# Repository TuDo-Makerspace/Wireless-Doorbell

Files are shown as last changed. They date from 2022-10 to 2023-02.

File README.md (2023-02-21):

# TU-DO Wireless Doorbell <!-- omit in toc -->

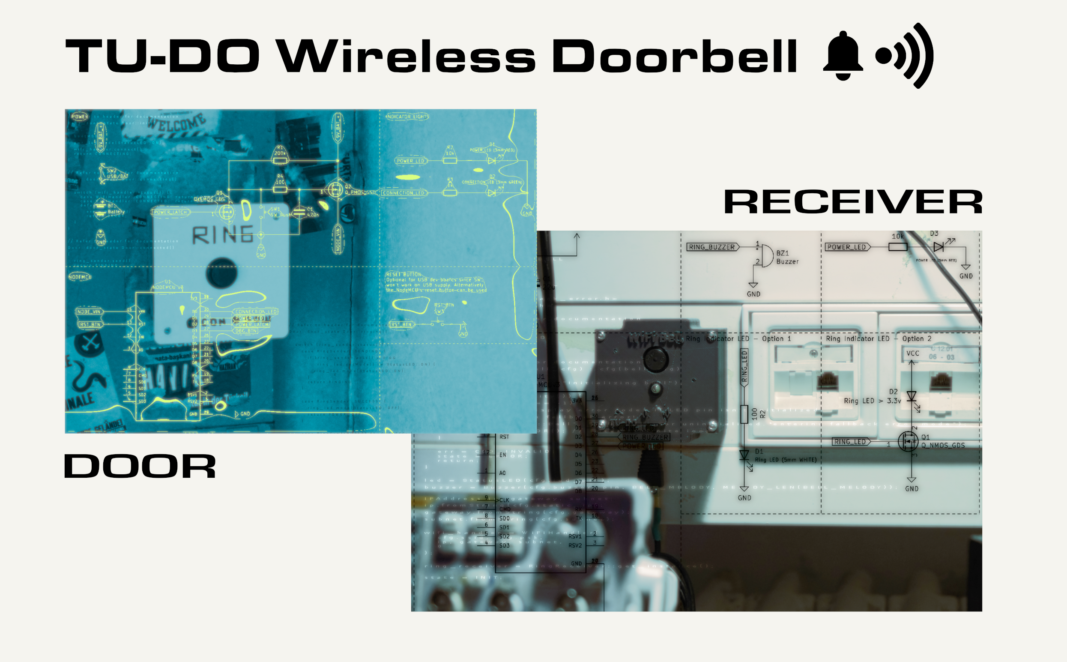
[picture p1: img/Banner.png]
Banner


A wireless doorbell based on the ESP8266

## Table Of Contents <!-- omit in toc -->

- [Overview](#overview)
	- [Doorbell Board](#doorbell-board)
	- [Receiver Board](#receiver-board)
- [Gerbers, BOMs, and Assembly](#gerbers-boms-and-assembly)
- [Configuring the Firmware and Flashing the Boards](#configuring-the-firmware-and-flashing-the-boards)
- [Firmware Structure](#firmware-structure)
- [License](#license)

## Overview

The TU-DO Wireless Doorbell is an open source and open hardware doorbell which runs over WiFi. The project utilizes the ESP8266 microcontroller, and includes two boards, one for the doorbell button and the other for the receiver.

### Doorbell Board

The doorbell board (also refered to as the "Door" board) is designed to be placed at the door and features a button to trigger the doorbell ring. It is powered by a 9V battery for easy installation.

The circuit of the doorbell board consists of:
- A button for triggering the doorbell ring
- Two indicator LEDs (one red and one green)
- An ESP8266 microcontroller
- A 9V battery
- A MOSFET power latch

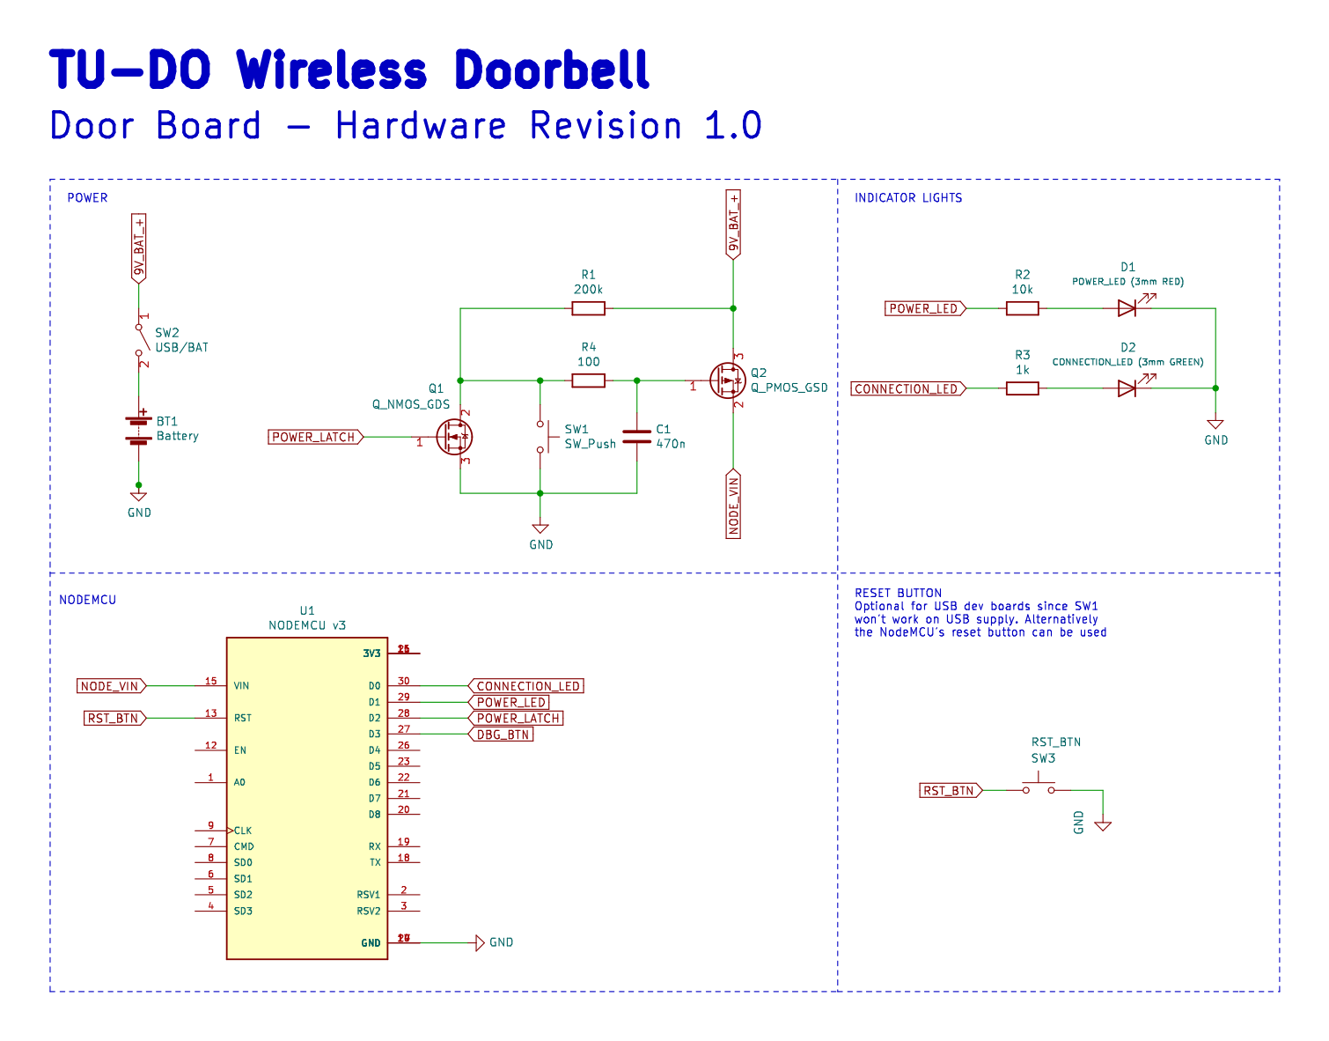
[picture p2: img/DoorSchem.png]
Door Board Schematic


When the ring button is pressed, power is supplied to the ESP8266 and the power latch is activated. The ESP8266 then connects to the WiFi network and sends a TCP packet to all receivers. After successful transmission, the power latch is unlatched and the device fully powers down. With normal usage, a 9V battery should last for multiple months.

During normal operation, the two indicator LEDs provide the following feedback to the user:
- The red LED indicates that the ESP8266 is powered
- The green LED indicates a successful transmission of the TCP packet

In case of an error however, the indicators are used for troubleshooting and will flash in a specific pattern, as described in the following table:

| LED Flash Pattern 				| Error 											|
|---|---|
| Power LED flashes 6x, Connection LED Off 	| Invalid `DoorCFG` provided (This can only occur if the Firmware code has been modified) 	|
| Power LED & Connection LED flash 3x 		| WiFi connection failed 									|
| Power LED flashes 3x, Connection LED Off 	| Failed to ring all Bells (Receivers) 								|
| Power LED & Connection LED flash 3x 		| Some, but not all Bells (Receivers) rang 							|
| Power LED & Connection LED flash alternately 	| `Door` class object improperly initialized (This can only occur if the Firmware code has been modified) |

For further debugging, the ESP8266 will also print a detailed log over the USB serial monitor at `115200` baud.

### Receiver Board

One or more receiver boards (also refered to as the "Bell" boards) are placed at locations where the doorbell ring is to be heard, and feature a buzzer for playing the doorbell ringtone. The receiver is continuously powered by a 5V-12V power supply and acts as a server, waiting for TCP packets from the doorbell board.

The circuit of the receiver board consists of:
- A buzzer for playing the doorbell ringtone
- A red power indicator LED
- A white ring indicator LED
- An ESP8266 microcontroller
- An optional power MOSFET (for driving a higher voltage ring indicator light, which would require a higher voltage power supply such as 12V)

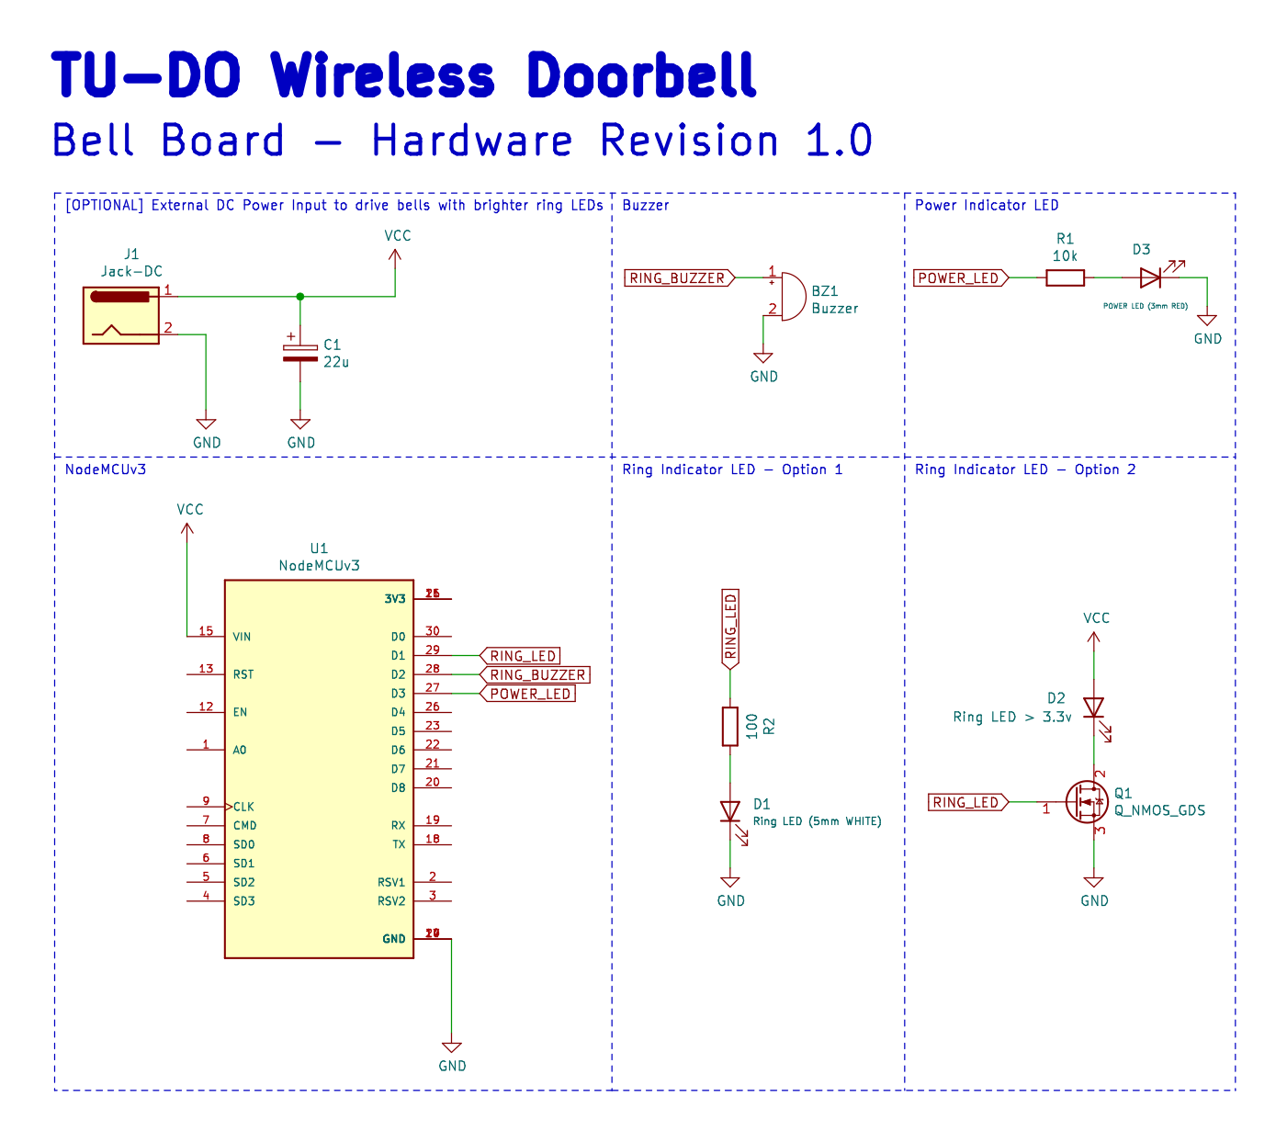
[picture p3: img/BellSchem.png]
Bell Board Schematic


When the ESP8266 on the receiver board receives a TCP packet from the doorbell board, it will play the doorbell ringtone on the buzzer and flash the white ring indicator LED to provide visual feedback.

Additionally, if an error occurs, the ring indicator LED and the buzzer are used for troubleshooting, as described in the following table:

| LED Flash Pattern 				 	 | Error 												 |
|---|---|
| LED continously flashes slowly, Buzzer is silent	 | No WiFi connection, the device is attempting to (re-)connect to the WiFi network			 |
| LED continously flashes quickly (250ms), Buzzer is silent | Invalid `BellCFG` provided (This can only occur if the Firmware code has been modified) 		 |
| LED continously flashes quickly (250ms), Buzzer beeps	 | `Bell` class object improperly initialized (This can only occur if the Firmware code has been modified) |

For further debugging, the ESP8266 will also print a detailed log over the USB serial monitor at `115200` baud.

## Gerbers, BOMs, and Assembly

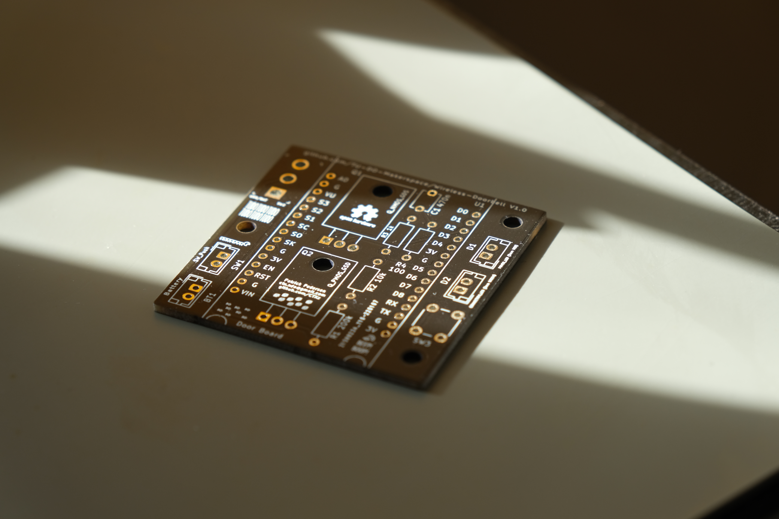
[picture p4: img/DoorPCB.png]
Door Board PCB


The Gerber files for the doorbell and receiver boards can be found in the `kicad/(BOARD)/gerbers` folder. An Interactive Bill Of Materials (IBOM) for the Door board is available [here](https://TU-DO-Makerspace.github.io/Wireless-Doorbell/door-ibom.html) and for the Bell board [here](https://TU-DO-Makerspace.github.io/Wireless-Doorbell/bell-ibom.html). These provide not only a list of all components, but also a visual representation of the PCB layout, showing where each component is placed. This can be particularly useful during the assembly process.

The PCB design utilizes many JST connectors, making it easy to incorporate the device into a variety of enclosures. If you have access to a 3D printer, you can also print the enclosures provided in the `STL` folder.

## Configuring the Firmware and Flashing the Boards

The firmware for the doorbell and receiver boards has been written using PlatformIO, and it is highly recommended to use it for flashing the boards. Before flashing the firmware, you need to configure all necessary settings such as WiFi credentials, the static door IP, the number of receivers, etc. in the `src/config.h` header file.

> **Important Note on IP Addresses:** The current version of the firmware requires all boards to have a static IP address, and the IP addresses of the receiver boards must be incremented after the doorbell board's IP. For example, if the doorbell board has IP `192.168.0.20`, the first receiver board must have IP `192.168.0.21`, the second receiver board must have IP `192.168.0.22`, and so on.

The IP addresses for the receiver boards can be configured in the [platformio.ini](platformio.ini) file. Currently, the targets are set up for the TU-DO Makerspace's network, but they can easily be changed to match your own setup.

To flash the boards, follow these steps:
1. Select the corresponding target in PlatformIO.
2. Remove the ESP8266 from the board that you wish to flash.
3. Connect the ESP8266 to your computer.
4. Click the upload button in PlatformIO.

> Note: Flashing the ESP8266 while it is inside the board may not work properly, so it is recommended to remove the ESP8266 from the board before flashing.

## Firmware Structure

The firmware code is organized in the `src` folder and is comprised of three main parts: `bell`, `door`, and `common`. The code for the doorbell and receiver boards is located in the `door` and `bell` folders, respectively, while code shared between the two is stored in the `common` folder.

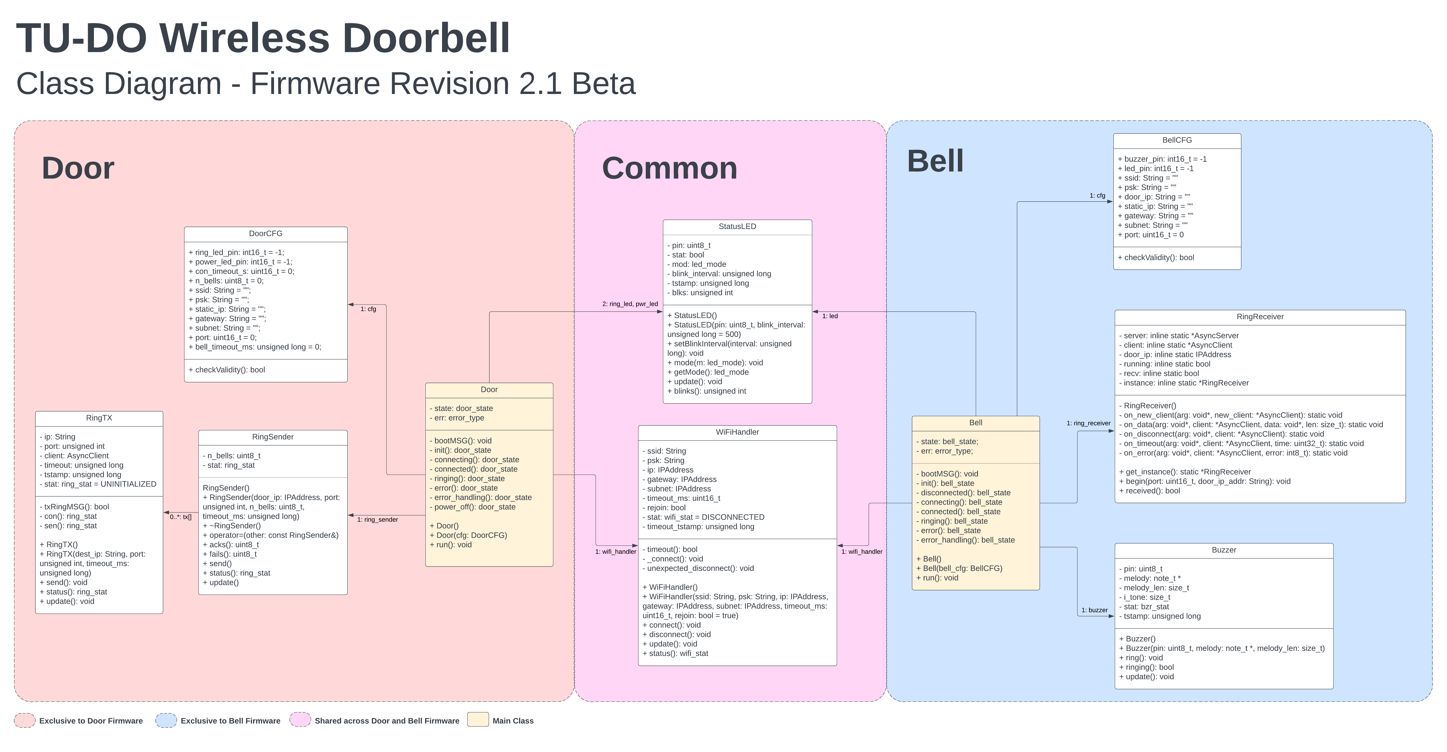
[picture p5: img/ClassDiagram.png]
Class Diagram


> Note: A PDF of the class diagram can be found [here](pdf/ClassDiagram.pdf).

The firmware was written in an object-oriented manner and heavily utilizes state machines. Each device is controlled by a main class such as `Door` for the doorbell and `Bell` for the receiver. These classes are then made up of subclasses that handle smaller tasks, such as the `Buzzer` class that manages the buzzer on the receiver and the `RingSender` class that handles the sending of TCP packets from the doorbell.

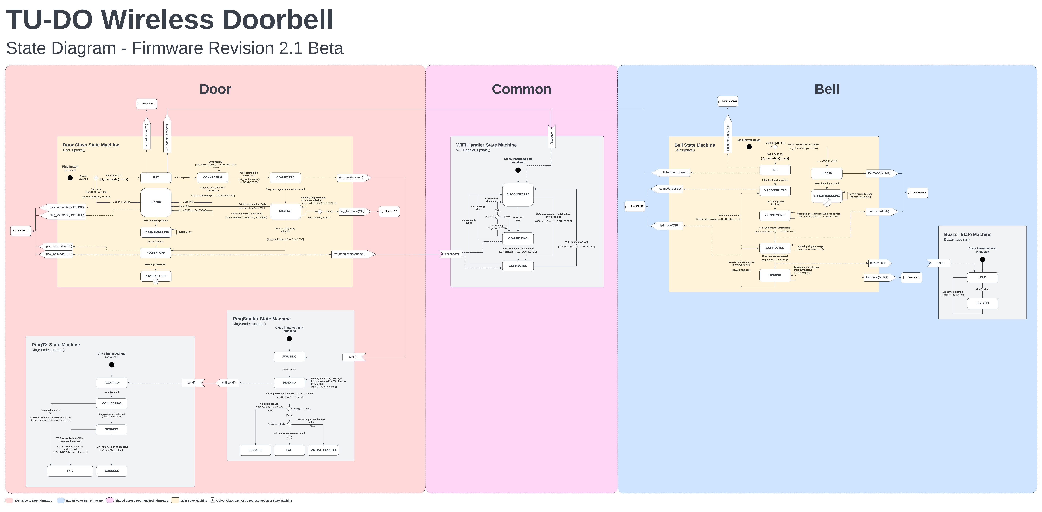
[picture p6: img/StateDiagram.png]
State Diagram


> Note: A PDF of the state diagram can be found [here](pdf/StateDiagram.pdf).

The codebase also generates a doxygen documentation that can be found [here](https://TU-DO-Makerspace.github.io/Wireless-Doorbell).

To fully comprehend the code, we highly recommend reading the comments within the code as well as consulting the doxygen documentation. Although we've endeavored to make the code self-explanatory and provided ample comments, feel free to reach out if you have any questions by opening an issue (make sure to include "QUESTION" in the issue title).

## License

The TU-DO Wireless Doorbell firmware is licensed under the GPLv3 license. The hardware is licensed under the TAPR Open Hardware License v2.0.

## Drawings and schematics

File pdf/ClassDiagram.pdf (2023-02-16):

Door | Common | Bell

# TU-DO Wireless Doorbell

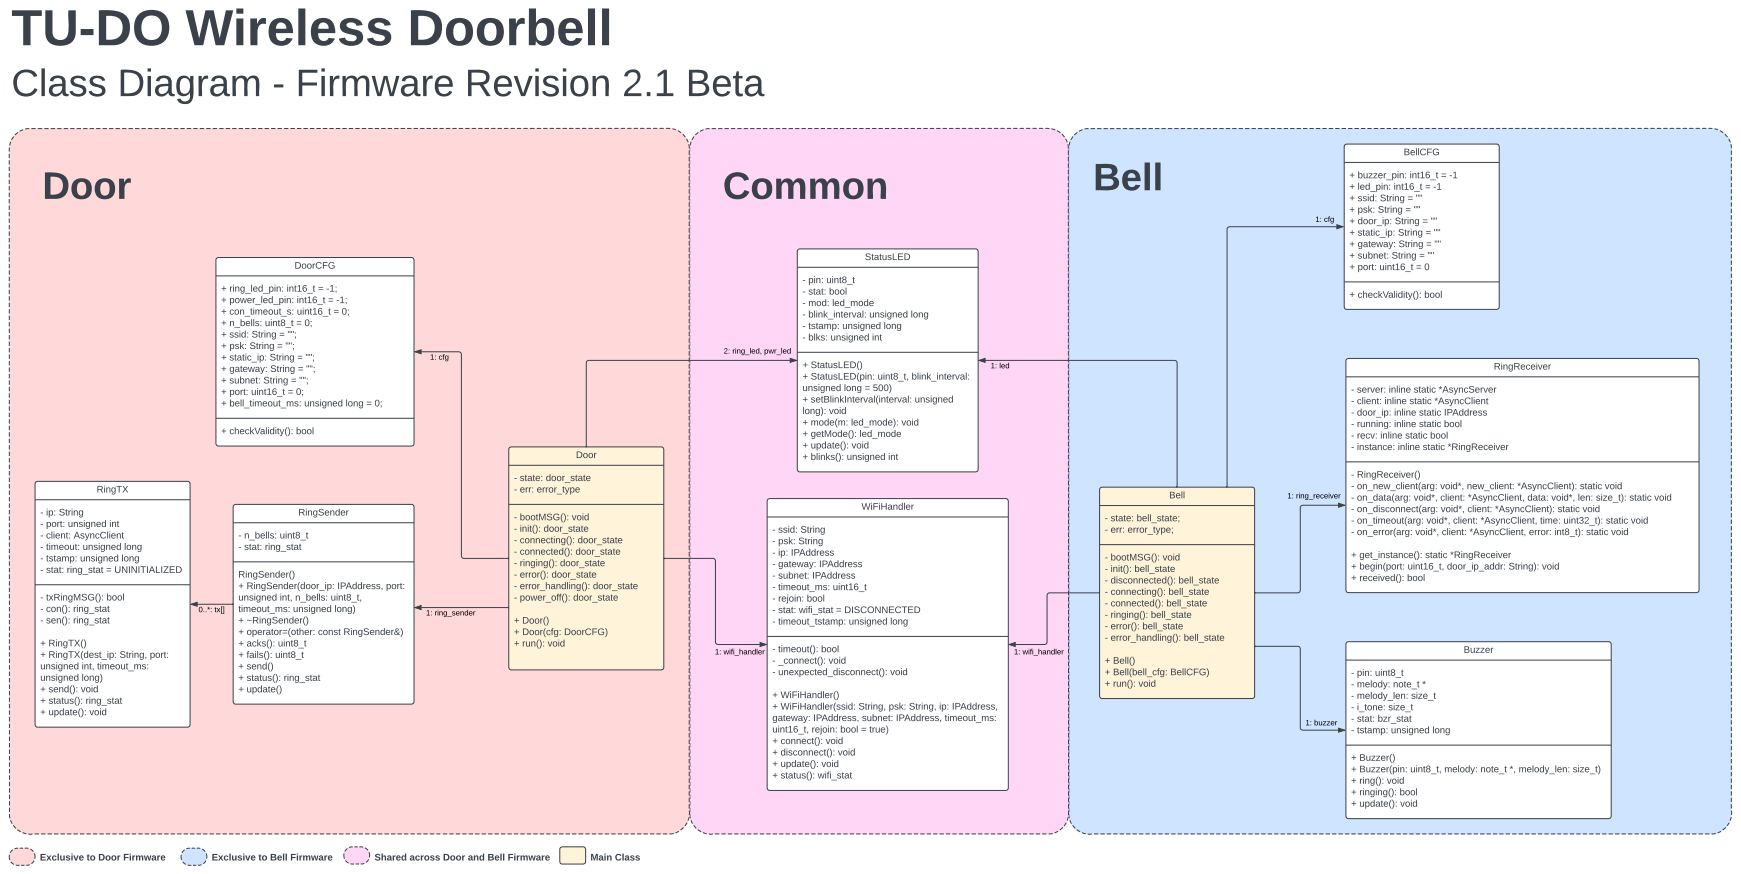
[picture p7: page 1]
Door; - state: door_state - err: error_type; - bootMSG(): void - init(): door_state - connecting(): door_state - connected(): door_state - ringing(): door_state - error(): door_state - error_handling(): door_state - power_off(): door_state; DoorCFG; + ring_led_pin: int16_t = -1; + power_led_pin: int16_t = -1; + con_timeout_s: uint16_t = 0; + n_bells: uint8_t = 0; + ssid: String = ""; + psk: String = ""; + static_ip: String = ""; + gateway: String = ""; + subnet: String = ""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

Class Diagram - Firmware Revision 2.1 Beta

- pin: uint8_t
- stat: bool
- mod: led_mode
- blink_interval: unsigned long
- tstamp: unsigned long
- blks: unsigned int

+ StatusLED()
+ StatusLED(pin: uint8_t, blink_interval:
unsigned long = 500)
+ setBlinkInterval(interval: unsigned
long): void
+ mode(m: led_mode): void
+ getMode(): led_mode
+ update(): void
+ blinks(): unsigned int

- server: inline static *AsyncServer
- client: inline static *AsyncClient
- door_ip: inline static IPAddress
- running: inline static bool
- recv: inline static bool
- instance: inline static *RingReceiver

- RingReceiver()
- on_new_client(arg: void*, new_client: *AsyncClient): static void
- on_data(arg: void*, client: *AsyncClient, data: void*, len: size_t): static void
- on_disconnect(arg: void*, client: *AsyncClient): static void
- on_timeout(arg: void*, client: *AsyncClient, time: uint32_t): static void
- on_error(arg: void*, client: *AsyncClient, error: int8_t): static void

- ip: String
- port: unsigned int
- client: AsyncClient
- timeout: unsigned long
- stat: ring_stat = UNINITIALIZED

+ get_instance(): static *RingReceiver
+ begin(port: uint16_t, door_ip_addr: String): void
+ received(): bool

RingSender()
+ RingSender(door_ip: IPAddress, port:
unsigned int, n_bells: uint8_t,
timeout_ms: unsigned long)
+ ~RingSender()
+ operator=(other: const RingSender&)
+ acks(): uint8_t
+ fails(): uint8_t
+ send()
+ status(): ring_stat
+ update()

+ Door()
+ Door(cfg: DoorCFG)
+ run(): void

+ RingTX()
+ RingTX(dest_ip: String, port:
unsigned int, timeout_ms:
unsigned long)
+ send(): void

+ WiFiHandler()
+ WiFiHandler(ssid: String, psk: String, ip: IPAddress,
gateway: IPAddress, subnet: IPAddress, timeout_ms:
uint16_t, rejoin: bool = true)
+ connect(): void
+ disconnect(): void
+ status(): wifi_stat

+ Buzzer()
+ Buzzer(pin: uint8_t, melody: note_t *, melody_len: size_t)
+ ring(): void
+ ringing(): bool

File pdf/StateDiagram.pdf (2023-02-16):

Door | Common | Bell

# TU-DO Wireless Doorbell

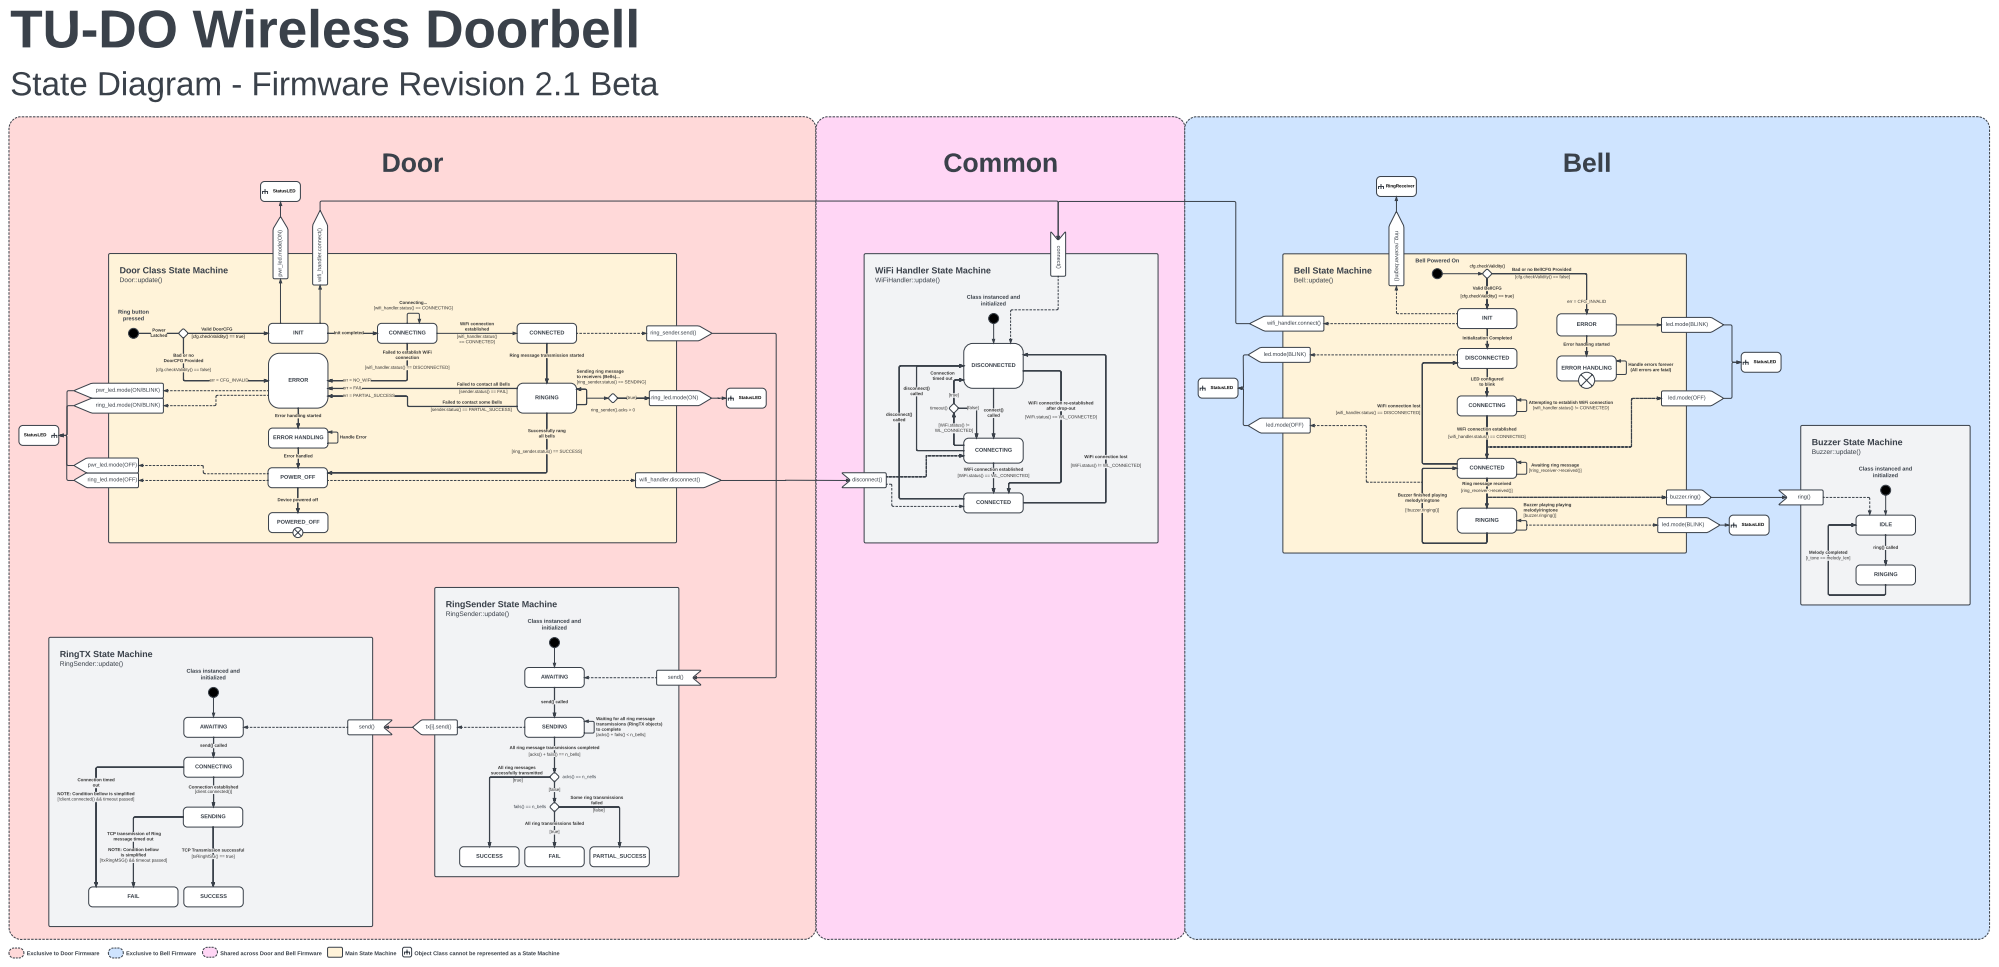
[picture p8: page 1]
StatusLED; IDLE; RINGING; ring() called; Melody completed [i_tone == melody_len]; ring(); INIT; DISCONNECTED; Initialization Completed; CONNECTING; LED configured to blink; CONNECTED; [wifi_handler.status() == DISCONNECTED]; [buzzer.ringing()]; [!buzzer.ringing()]; ERROR; ERROR HANDLING; err = CFG_INVALID; cfg.checkValidity(); buzzer.ring(); wifi_handler.connect(); ring _receiv; e gin(); [WiFi.status() == WL_CONNECTED]; connect() called; [WiFi.status() != WL_CONNECTED]; Connection timed out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

State Diagram - Firmware Revision 2.1 Beta

Bell Powered On

Door Class State Machine
Door::update()

WiFi Handler State Machine
WiFiHandler::update()

Bell State Machine
Bell::update()

Bad or no BellCFG Provided
[cfg.checkValidity() == false]

Valid BellCFG
[cfg.checkValidity() == true]

Class instanced and
initialized

led.mode(BLINK)

Valid DoorCFG

Error handling started

Bad or no DoorCFG Provided

Failed to establish WiFi
connection

Ring message transmission started

Handle errors forever
(All errors are fatal)

Sending ring message
to receivers (Bells)...

[ring_sender.status() == SENDING] Failed to contact all Bells
[sender.status() == FAIL]

pwr_led.mode(ON/BLINK)

led.mode(OFF)

ring_led.mode(ON/BLINK)

Failed to contact some Bells
[sender.status() == PARTIAL_SUCCESS]

WiFi connection re-established

Attempting to establish WiFi connection
[wifi_handler.status() != CONNECTED]

after drop-out

WiFi connection lost

WiFi connection established
[wifi_handler.status() == CONNECTED]

Buzzer State Machine
Buzzer::update()

[WiFi.status() != WL_CONNECTED]

Awaiting ring message
[!ring_receiver->received()]

[WiFi.status() == WL_CONNECTED]

Ring message received
[ring_receiver->received()]

Buzzer finished playing melody/ringtone

Device powered off

Buzzer playing playing melody/ringtone

RingSender State Machine
RingSender::update()

RingTX State Machine

Waiting for all ring message
transmissions (RingTX objects)
to complete
[acks() + fails() < n_bells]

All ring message transmissions completed

All ring messages
successfully transmitted

NOTE: Condition bellow is simplified
[!client.connected() && timeout passed]

Some ring transmissions

All ring transmissions failed

TCP transmission of Ring message timed out

NOTE: Condition bellow
is simplified

TCP Transmission successful
[txRingMSG() == true]

[!txRingMSG() && timeout passed]

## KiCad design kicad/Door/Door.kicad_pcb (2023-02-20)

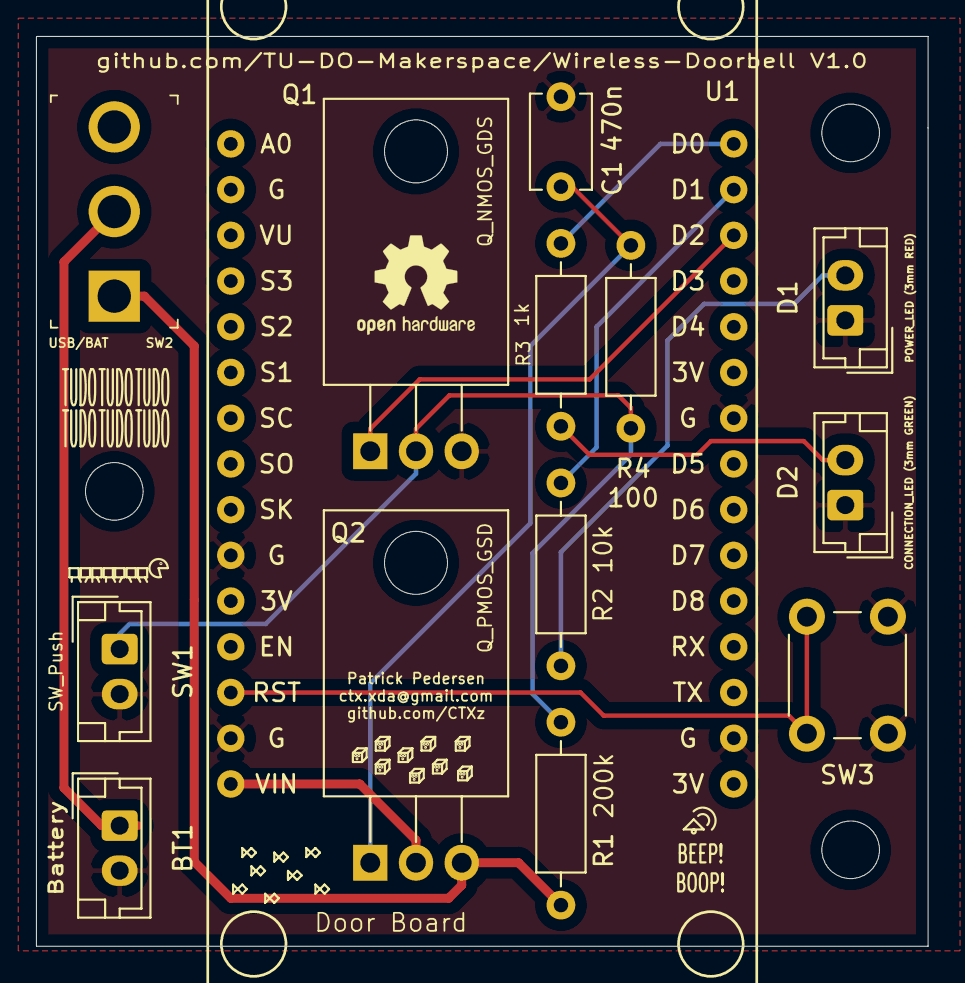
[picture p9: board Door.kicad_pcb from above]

Board: 2 copper layers, 49.5 x 50.5 mm, 14 parts (0 on the bottom side), 12 nets.

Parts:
BT1: Battery; JST_EH_B2B-EH-A_1x02_P2.50mm_Vertical
C1: 470n; C_Disc_D5.1mm_W3.2mm_P5.00mm
D1: POWER_LED (3mm RED); JST_EH_B2B-EH-A_1x02_P2.50mm_Vertical
D2: CONNECTION_LED (3mm GREEN); JST_EH_B2B-EH-A_1x02_P2.50mm_Vertical
Q1: Q_NMOS_GDS; TO-220-3_Horizontal_TabDown
Q2: Q_PMOS_GSD; TO-220-3_Horizontal_TabDown
R1: 200k; R_Axial_DIN0207_L6.3mm_D2.5mm_P10.16mm_Horizontal
R2: 10k; R_Axial_DIN0207_L6.3mm_D2.5mm_P10.16mm_Horizontal
R3: 1k; R_Axial_DIN0207_L6.3mm_D2.5mm_P10.16mm_Horizontal
R4: 100; R_Axial_DIN0207_L6.3mm_D2.5mm_P10.16mm_Horizontal
SW1: SW_Push; JST_EH_B2B-EH-A_1x02_P2.50mm_Vertical
SW2: USB/BAT; Toggle_Switch_100SP1T1B4M2QE
SW3: RST_BTN; SW_PUSH_6mm
U1: NODEMCU v3; NodeMCU-LoLinV3

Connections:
9V_BAT_+: Q2.3, R1.2, SW2.1
CONNECTION_LED: R3.1, U1.30
GND: BT1.2, C1.2, D1.1, D2.1, Q1.3, SW1.2, SW3.2, U1.10, U1.14, U1.17, U1.24
NODE_VIN: Q2.2, U1.15
unnamed: BT1.1, SW2.2
unnamed: C1.1, Q2.1, R4.2
unnamed: D1.2, R2.2
unnamed: D2.2, R3.2
unnamed: Q1.2, R1.1, R4.1, SW1.1
POWER_LATCH: Q1.1, U1.28
POWER_LED: R2.1, U1.29
RST_BTN: SW3.1, U1.13

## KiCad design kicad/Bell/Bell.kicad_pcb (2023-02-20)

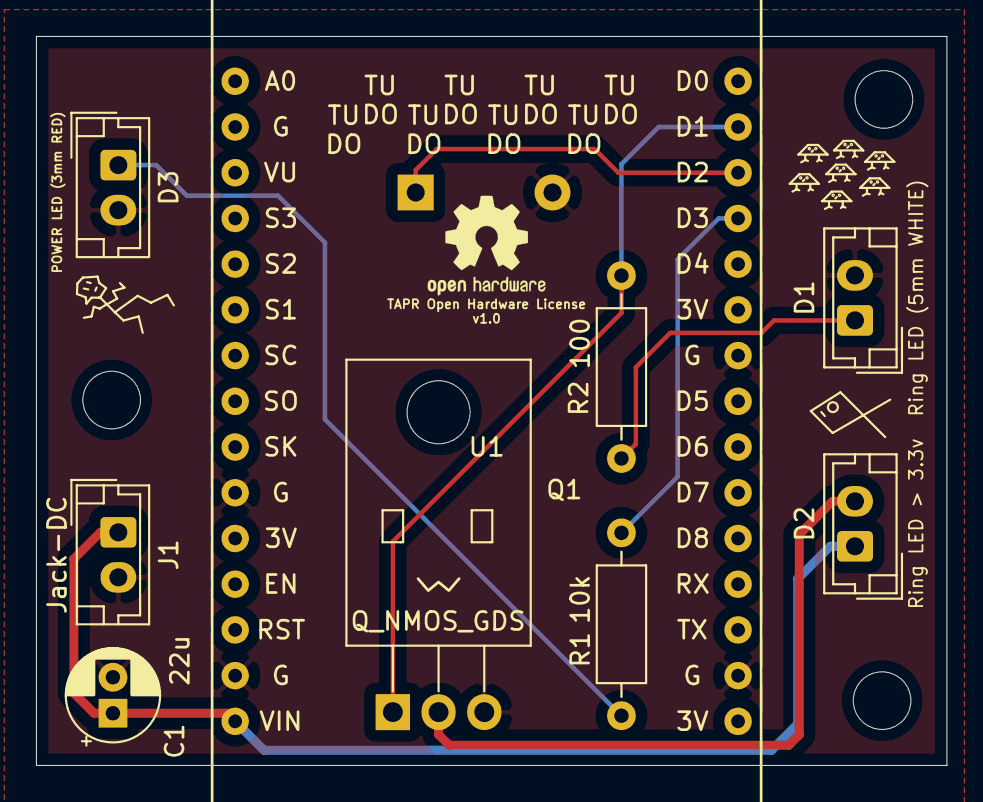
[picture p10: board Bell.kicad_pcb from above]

Board: 2 copper layers, 50.6 x 40.5 mm, 10 parts (1 on the bottom side), 8 nets.

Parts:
BZ1: Buzzer; Buzzer_12x9.5RM7.6
C1: 22u; CP_Radial_D5.0mm_P2.00mm
D1: Ring LED (5mm WHITE); JST_EH_B2B-EH-A_1x02_P2.50mm_Vertical
D2: Ring LED > 3.3v; JST_EH_B2B-EH-A_1x02_P2.50mm_Vertical
D3: POWER LED (3mm RED); JST_EH_B2B-EH-A_1x02_P2.50mm_Vertical
J1: Jack-DC; JST_EH_B2B-EH-A_1x02_P2.50mm_Vertical
Q1: Q_NMOS_GDS; TO-220-3_Horizontal_TabDown
R1: 10k; R_Axial_DIN0207_L6.3mm_D2.5mm_P10.16mm_Horizontal
R2: 100; R_Axial_DIN0207_L6.3mm_D2.5mm_P10.16mm_Horizontal
U1: NodeMCUv3; NodeMCU-LoLinV3

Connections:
GND: BZ1.2, C1.2, D1.2, D3.2, J1.2, Q1.3, U1.10, U1.14, U1.17, U1.24
unnamed: D1.1, R2.1
unnamed: D2.2, Q1.2
unnamed: D3.1, R1.1
POWER_LED: R1.2, U1.27
RING_BUZZER: BZ1.1, U1.28
RING_LED: Q1.1, R2.2, U1.29
VCC: C1.1, D2.1, J1.1, U1.15

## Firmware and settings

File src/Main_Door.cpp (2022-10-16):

#ifdef TARGET_DEV_DOOR

#include <ESP8266WiFi.h>
#include <ESPAsyncTCP.h>

#include <log.h>
#include <ring_msg.h>
#include <StatusLED.h>
#include <DoorUXHandler.h>

#include "config.h"

#define SEARCHING_BELL 0x0
#define BELL_FOUND 0x1
#define BELL_NOT_FOUND 0x2

#define LATCH_POWER() digitalWrite(DOOR_POWER_LATCH, HIGH)
#define UNLATCH_POWER() digitalWrite(DOOR_POWER_LATCH, LOW)

static uint8_t bells_remaining = N_BELLS;
static uint8_t bell_found = SEARCHING_BELL;

static DoorUXHandler door_ux(N_BELLS, DOOR_RING_LED, DOOR_POWER_LED);

void onConnect(void* arg, AsyncClient* client) {
	log_msg("onConnect", "Connected to " + String(client->remoteIP().toString()));	
	
	const char msg = RING_MSG;
	client->add(&msg, sizeof(msg));
	
	if (client->send())
		log_msg("onConnect", "Sent ring message to " + String(client->remoteIP().toString()));
	else
		log_msg("onConnect", "Failed to send ring message to " + String(client->remoteIP().toString()));

	log_msg("onConnect", "Closing connection to " + String(client->remoteIP().toString()));
	client->close();

	door_ux.bellAcknowledged();
	bell_found = BELL_FOUND;
}

void onDisconnect(void* arg, AsyncClient* client) {
	bells_remaining--;

	if (bell_found == SEARCHING_BELL)
		bell_found = BELL_NOT_FOUND;

	log_msg("onDisconnect", "Disconnected from bell (" + String(bells_remaining) + " remaining)");

	door_ux.bellDisconnected();
}

void boot_msg()
{
        log_msg("boot_msg", "---------------------------------------------------------------------------");
        log_msg("boot_msg", "___       __   __"); 
        log_msg("boot_msg", " |  |  | |  \\ /  \\");
        log_msg("boot_msg", " |  \\__/ |__/ \\__/");                
        log_msg("boot_msg", "");                                     
        log_msg("boot_msg", " __   __   __   __   __   ___");     
        log_msg("boot_msg", "|  \\ /  \\ /  \\ |__) |__) |__  |    |");
        log_msg("boot_msg", "|__/ \\__/ \\__/ |  \\ |__) |___ |___ |___");
        log_msg("boot_msg", "");
        log_msg("boot_msg", "Author:\t\tPatrick Pedersen");
        log_msg("boot_msg", "License:\t\tGPLv3");
        log_msg("boot_msg", "Build date:\t\t" + String(__DATE__));
        log_msg("boot_msg", "Software Revision:\t" + String(SW_REV) + "_DOOR");
        log_msg("boot_msg", "Hardware Revision:\t" + String(HW_REV) + "_DOOR");
        log_msg("boot_msg", "Source code:\t\thttps://github.com/TU-DO-Makerspace/Wireless-Doorbell");
        log_msg("boot_msg", "Device type:\t\tDoor");
        log_msg("boot_msg", "Targeted SSID:\t" + String(WIFI_SSID));
        log_msg("boot_msg", "---------------------------------------------------------------------------");
        log_msg("boot_msg", "");
}

void setup()
{
	// Latch Power
        pinMode(DOOR_POWER_LATCH, OUTPUT);
        LATCH_POWER();
        DBG_LOG("setup", "Power latched");
	door_ux.update();

	Serial.begin(115200);
	Serial.println();

#ifdef DEBUG
	boot_msg();
#endif

        WiFi.begin(WIFI_SSID, WIFI_PSK);

	IPAddress ip;
	ip.fromString(DOOR_IP);

	IPAddress gateway;
	gateway.fromString(GATEWAY); 

	IPAddress subnet(255,255,255,0); 

	WiFi.config(ip, gateway, subnet);

	log_msg("setup", "Attempting to connect to: " + String(WIFI_SSID));

	if (WiFi.waitForConnectResult() != WL_CONNECTED) {
		door_ux.wifiError();
		return;
	}

	log_msg("setup", "Connected to " + String(WIFI_SSID));
	log_msg("setup", "IP address: " + WiFi.localIP().toString());

	AsyncClient *clients[N_BELLS];
	for (uint8_t i = 0; i < N_BELLS; i++) {
		AsyncClient *client = new AsyncClient();
		client->onConnect(&onConnect, client);
		client->onDisconnect(&onDisconnect, client);
		clients[i] = client;
	}

	const String door_ip_str = DOOR_IP;

	for (uint8_t i = 0; i < N_BELLS; i++) {
		String bell_ip_str = door_ip_str;
		bell_ip_str[bell_ip_str.length() - 1] = (i+1) + '0';
		log_msg("setup", "Attempting to connect to bell: " + bell_ip_str);
		clients[i]->connect(bell_ip_str.c_str(), TCP_PORT);
	}
}

void power_off() {
	UNLATCH_POWER();

#ifdef DEBUG
	digitalWrite(DOOR_RING_LED, LOW);
	digitalWrite(DOOR_POWER_LED, LOW);
	
	static bool unlatch_logged = false;
	if (!unlatch_logged) {
		log_msg("power_off", "Power unlatched");
		unlatch_logged = true;
	}
#endif

}

void loop()
{
	if (door_ux.done()) {
		power_off();
		return;
	}

	door_ux.update();

}

#endif

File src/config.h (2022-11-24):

/*
 * Copyright (C) 2022 Patrick Pedersen, TU-DO Makerspace

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
 */

/**
 * @file config.h
 * @author Patrick Pedersen, TU-DO Makerspace
 * @brief Configuration file to configure the door and bell firmware
 */

#pragma once

#include <bell/melodies.h>

// WiFi

#define GATEWAY "192.168.0.1"

#ifndef GATEWAY
#warning No gateway specified! Assuming 192.168.0.1!
#define GATEWAY "192.168.0.1"
#endif

#define WIFI_SSID "TUDOMakerspace"
#define WIFI_PSK "SECRET"

// Door Host ID
#ifdef DEBUG
#define DOOR_IP "192.168.0.30"
#else
#define DOOR_IP "192.168.0.20"
#endif

// TCP
#define TCP_PORT 8888

/////////////////////////////////////
// DOOR SPECIFIC CONFIGURATION
/////////////////////////////////////

#ifdef TARGET_DEV_DOOR

#define DOOR_N_BELLS 1

#if DOOR_N_BELLS > 9
#error DOOR_N_BELLS must be less than 10!
#endif

// Pins & Peripherals
#define DOOR_POWER_LED D1
#define DOOR_POWER_LATCH D2
#define DOOR_RING_LED D0

// Revision
#define SW_REV "2.1.0_BETA"
#define HW_REV "1.0.0"

// Timeouts
#define DOOR_CONNECT_TIMEOUT_S 20
#define DOOR_BELL_TCP_TIMEOUT_MS 10000

#define DOOR_NO_BELLS_BLINKS 3
#define DOOR_PARTIAL_SUCCESS_BLINKS 3
#define DOOR_NO_WIFI_BLINKS 3
#define DOOR_CFG_INVALID_BLINKS 6

#endif

/////////////////////////////////////
// BELL SPECIFIC CONFIGURATION
/////////////////////////////////////

#ifdef TARGET_DEV_BELL

#ifndef BELL_IP
#error No IP address specified! Please define BELL_IP in the build flags (platformio.ini)!
#endif

// Revision
#define SW_REV "2.1.0_BETA"
#define HW_REV "1.0.0"

// Pins
#define BELL_LED D1
#define BELL_BUZZER D2

// Melody (See melodies.h)
#ifdef DEBUG
#define BELL_MELODY DEBUG_CHIME
// #define BELL_SILENT // Uncomment to disable bell
#elif !defined(BELL_MELODY)
#define BELL_MELODY DEFAULT_CHIME
#endif

// Indicators/Error messages
#define BELL_LED_BLINK_INTERVAL NOTE_DURATION //ms
#define BELL_LED_CONNECTING_BLINK_INTERVAL 1000 //ms

#endif // TARGET_DEV_BELL

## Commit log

2021-10-24 SQUASH: Log: Improved serial out logging Beacon: SSID, PWD and timeout are now set in the constructor Beacon: Fixed status() still returning TIMEOUT after calling stop() Scanner: SSID and PWD are now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
    [Main_Door.cpp]
2021-10-29 Main_Door: Keep power LED on until full shut down Main_Door: Added LATCH_POWER and UNLATCH_POWER macros
2021-11-01 Beacon: Hide network on non-debug builds Main_Door: Added power logs
2021-11-01 Main_Door: Improved Power Unlatch log message
2021-11-01 Main_Door: Stop beacon on device shut-down to give bells enough time to confirm connection
2021-11-30 Added Schematics
    [Bell.kicad_pcb, Bell.sch, Door.kicad_pcb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]
2021-12-06 PCB: Door: Set pull-up resistor to 200k to give ESP enough time to boot
    [Door.sch]
2021-12-07 PCB: Added PCB for Door board
    [Door.sch]
2022-01-06 Kicad: Finished 1st PCB revision
    [Bell-B_Cu.gbr, Bell-B_Mask.gbr, Bell-B_Paste.gbr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]
2022-01-25 Kicad: Updated to v6.0
    [Bell.kicad_pcb, Bell.kicad_sch, Door.kicad_pcb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]
2022-10-15 Initial commit of SW revision 2.0.0_ALPHA
    Software revision 2.0.0 no longer operates decentralized, but instead
    now makes use of a local network connection.
    Bells:
    The bells are constantly connected to our wireless network and await a
    TCP package from the door. Once a valid TCP package has been received,
    the bell will ring.
    Door:
    Upon button press, the transmitter will establish a connection to the
    wireless network and send out a RING_MSG tcp packet to all bells
    attached to the network.
    The software relies on a static pool of host IDs. At the moment, the door
    must be assigned a host ID ending with 0 (ex. 192.168.0.20). The bells should
    be assigned to the following up host ID's (ex. 192.16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
    [Main_Door.cpp, config.h]
2022-10-15 Bell: Implemented update method pattern + Handle LED flashing
2022-10-16 Added a Mutex class to prevent mutual access on peripherals (ex. the LED)
2022-10-16 Main_Bell: Do not perform ip check in debug build
    During debugging it is often desired to send tcp packets from
    any host device.
2022-10-16 Bell: Keep LED on during ring instead of flashing it
    Epileptics will love this commit
2022-10-16 Door: Addeed DoorUXHandler
    Potentially might rename this into door LED handler or something. It's current job is
    to asynchronously handle the LEDs on the door.
    I'm not too happy with this solution but it's better than the spaghetti code in the Main_Door.cpp file
    before
2022-10-16 Door: Fixed device remaining on if no WiFi connection can be established
    [Main_Door.cpp, config.h]
2022-10-25 v2.1.0: Major refactor of door code
    The door code has been completely overhauled and now consists of a main
    Door class, which is configured by a DoorCFG object, as well has a WiFiHandler class, a RingSender class and
    a RingTX class.
    To ensure processes run "asynchronously", all classes are implemented as state machines.
    Door
    ----
    The main Door class.
    This class handles the main logic of the door transmitter. Everything from initialization,
    to error handling and to most importantly instancing and utilizing the WifiHandler and RingSender.
    DoorCFG
    ---
    Builder class for Door class.
    The DoorCFG class is used to configure a Door class instance. It exposes a variety of parameter members
    as well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
    [Main_Door.cpp]
2022-11-20 Reformatted some switch statements
2023-02-15 README: Added images
    [Bell.kicad_sch, Door.kicad_sch]
2023-02-16 Door: Disconnect from wifi during power-off
2023-02-16 README: Upadted Door schematic to be more consistent
2023-02-17 PCBs: Added iboms
2023-02-17 README: Clarify that there can be multiple Bell boards
2023-02-20 Kicad: Updated Schematics and PCBs to Kicad v7.0
    [Bell.kicad_pcb, Bell.kicad_sch, Door.kicad_pcb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]

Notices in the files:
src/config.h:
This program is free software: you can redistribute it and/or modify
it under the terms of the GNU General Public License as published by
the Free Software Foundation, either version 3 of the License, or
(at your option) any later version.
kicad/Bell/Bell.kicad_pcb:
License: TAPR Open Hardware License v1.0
